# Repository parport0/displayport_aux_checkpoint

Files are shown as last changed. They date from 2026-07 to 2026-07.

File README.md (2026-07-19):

# displayport\_aux\_checkpoint 

An RP2040-powered box to be plugged between your computer and the monitor.

See also:

* [dvi_i2c_checkpoint](https://github.com/parport0/dvi_i2c_checkpoint)
* [ddcci_injector](https://github.com/parport0/ddcci_injector)
* [ddcci_dongle](https://github.com/parport0/ddcci_dongle)

Made to be manufactured at JLCPCB,

* JLC04161H-7628
* NanYa NP-155F

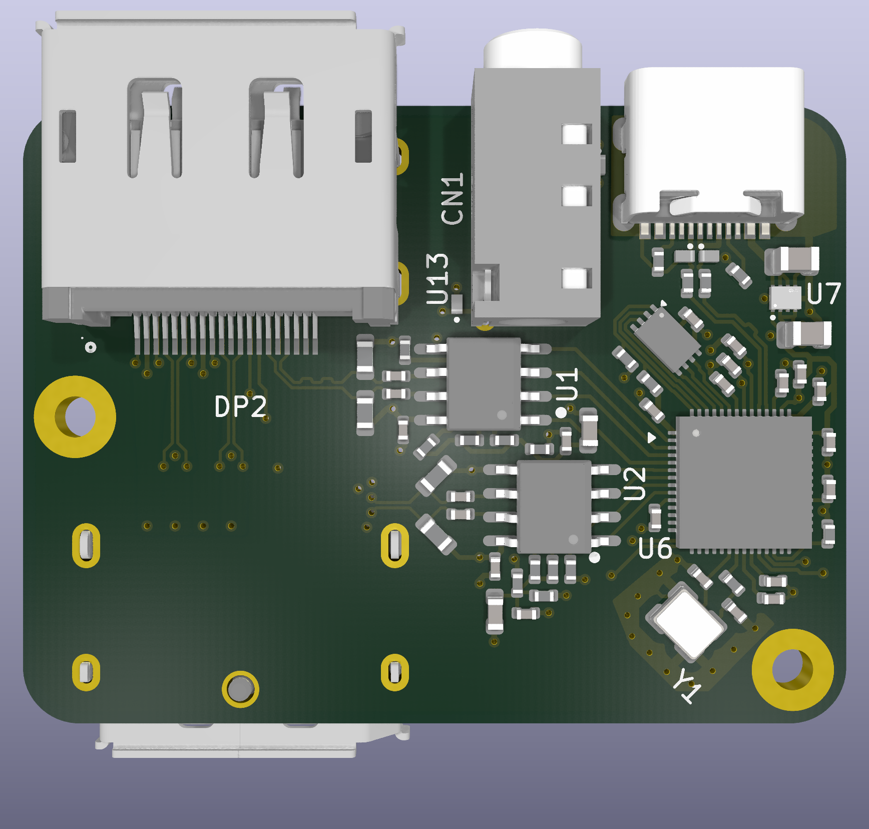
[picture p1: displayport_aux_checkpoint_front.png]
Front of the PCB


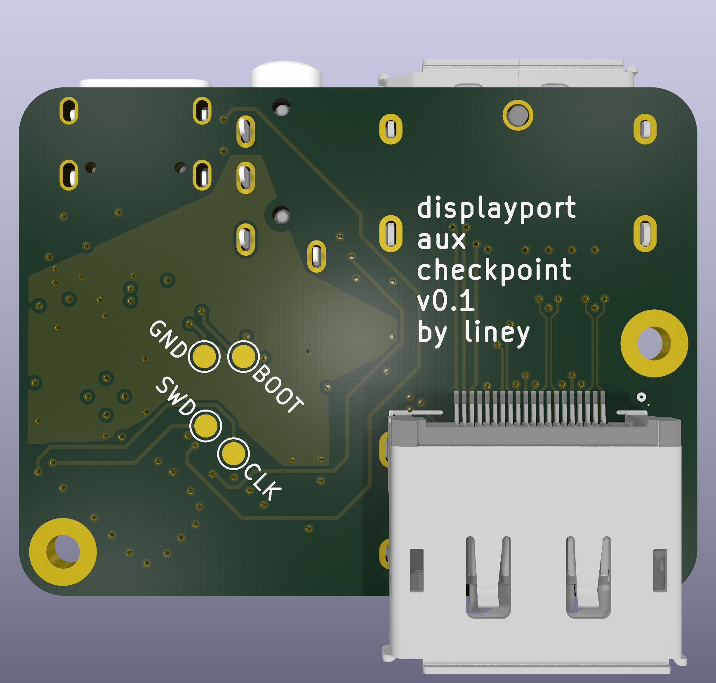
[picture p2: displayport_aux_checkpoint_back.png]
Back of the PCB


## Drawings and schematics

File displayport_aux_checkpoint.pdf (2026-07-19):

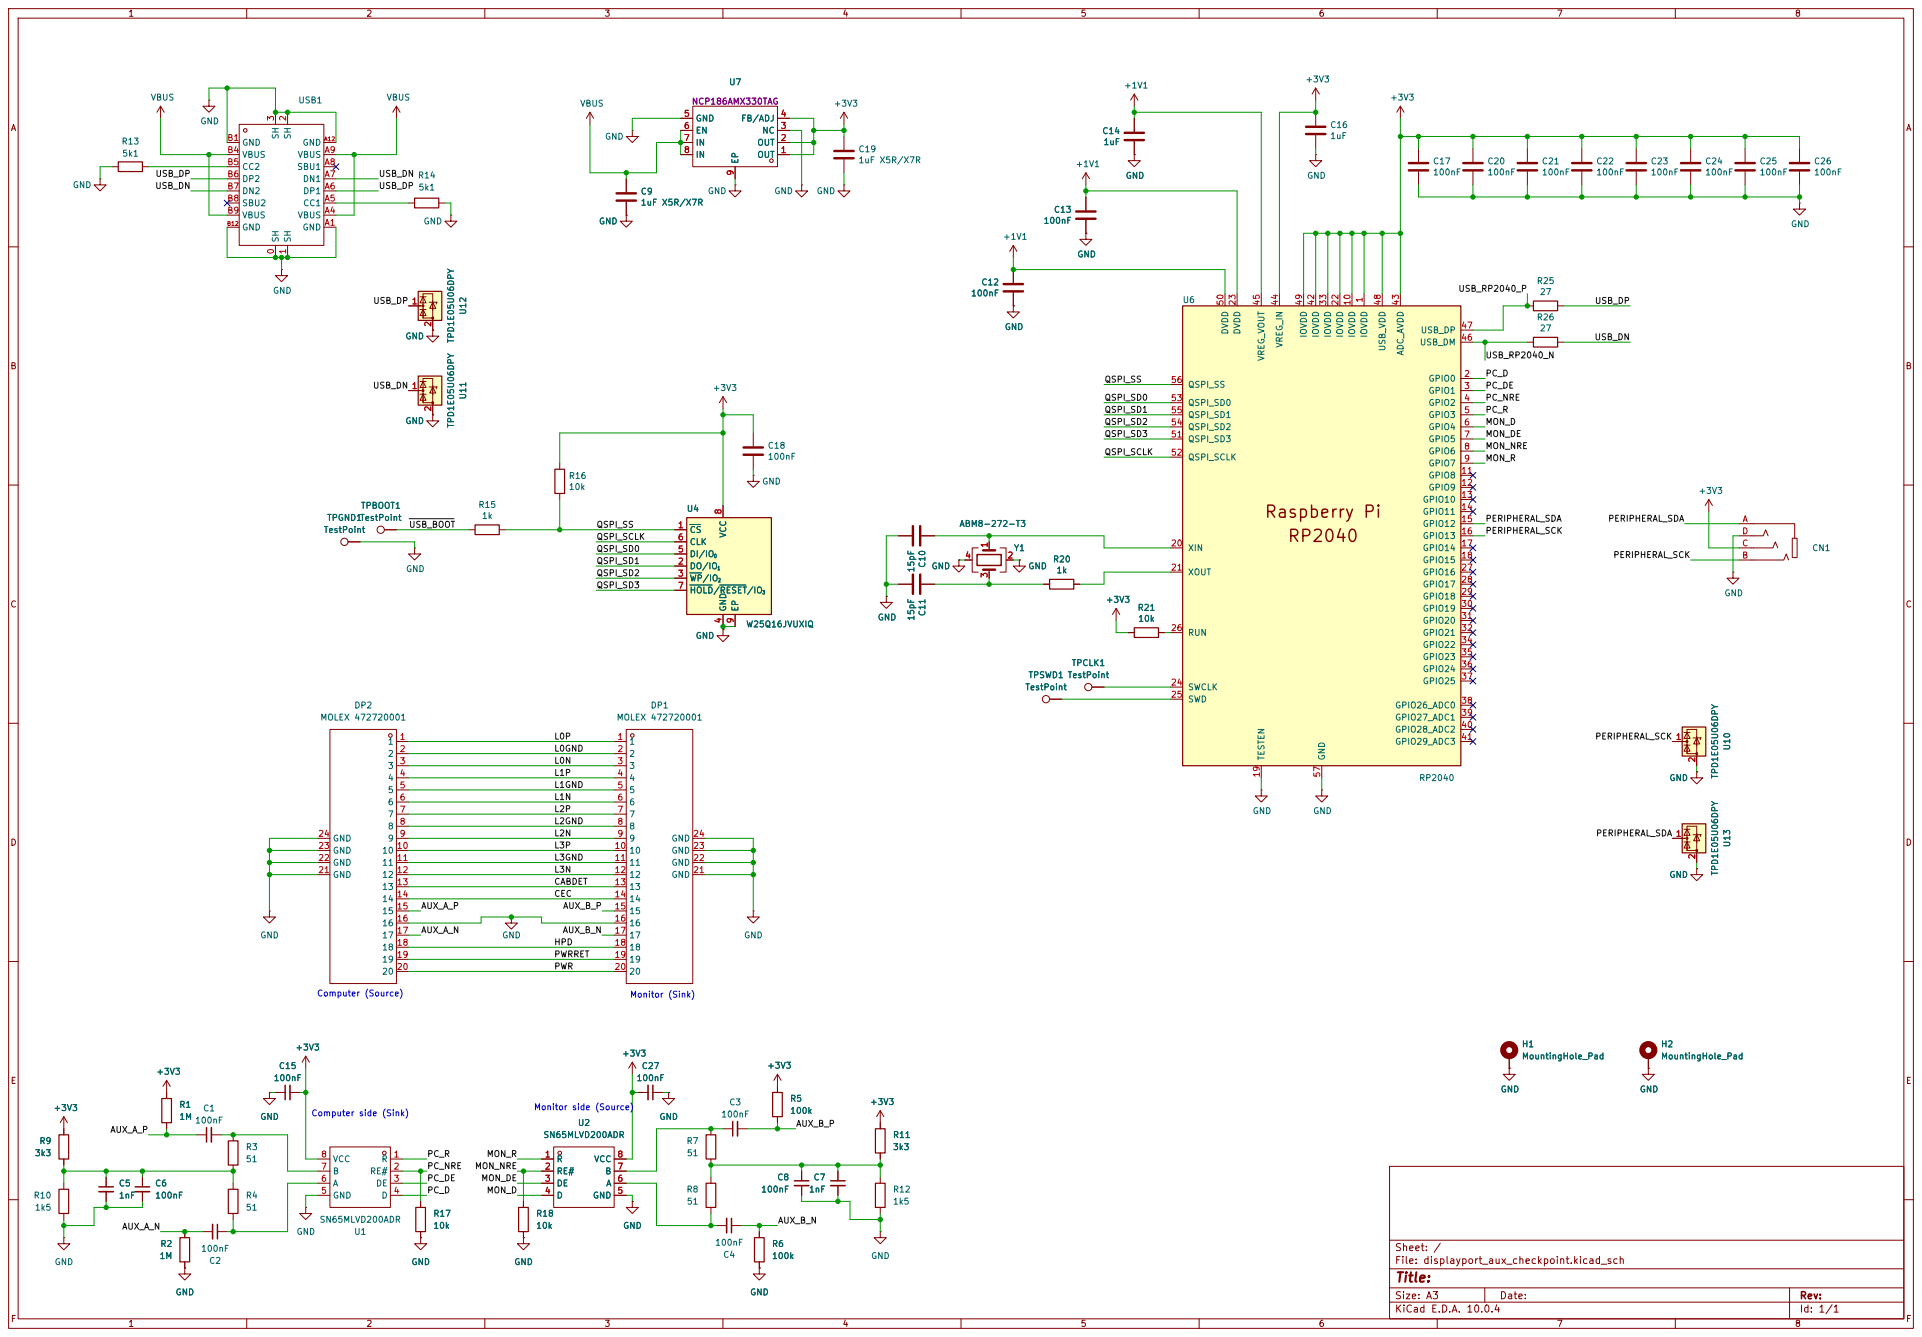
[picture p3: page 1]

3 GND A1 VBUS A4 CC1 A5 DP1 A6 DN1 A7 SBU1 A8 VBUS A9 GND A12 GND B1
GND

4 DI/IO0 5 CLK 6 HOLD/RESET/IO3 7 VCC

Size: A3 | Rev: | F Date:
KiCad E.D.A. 10.0.4 | Id: 1/1

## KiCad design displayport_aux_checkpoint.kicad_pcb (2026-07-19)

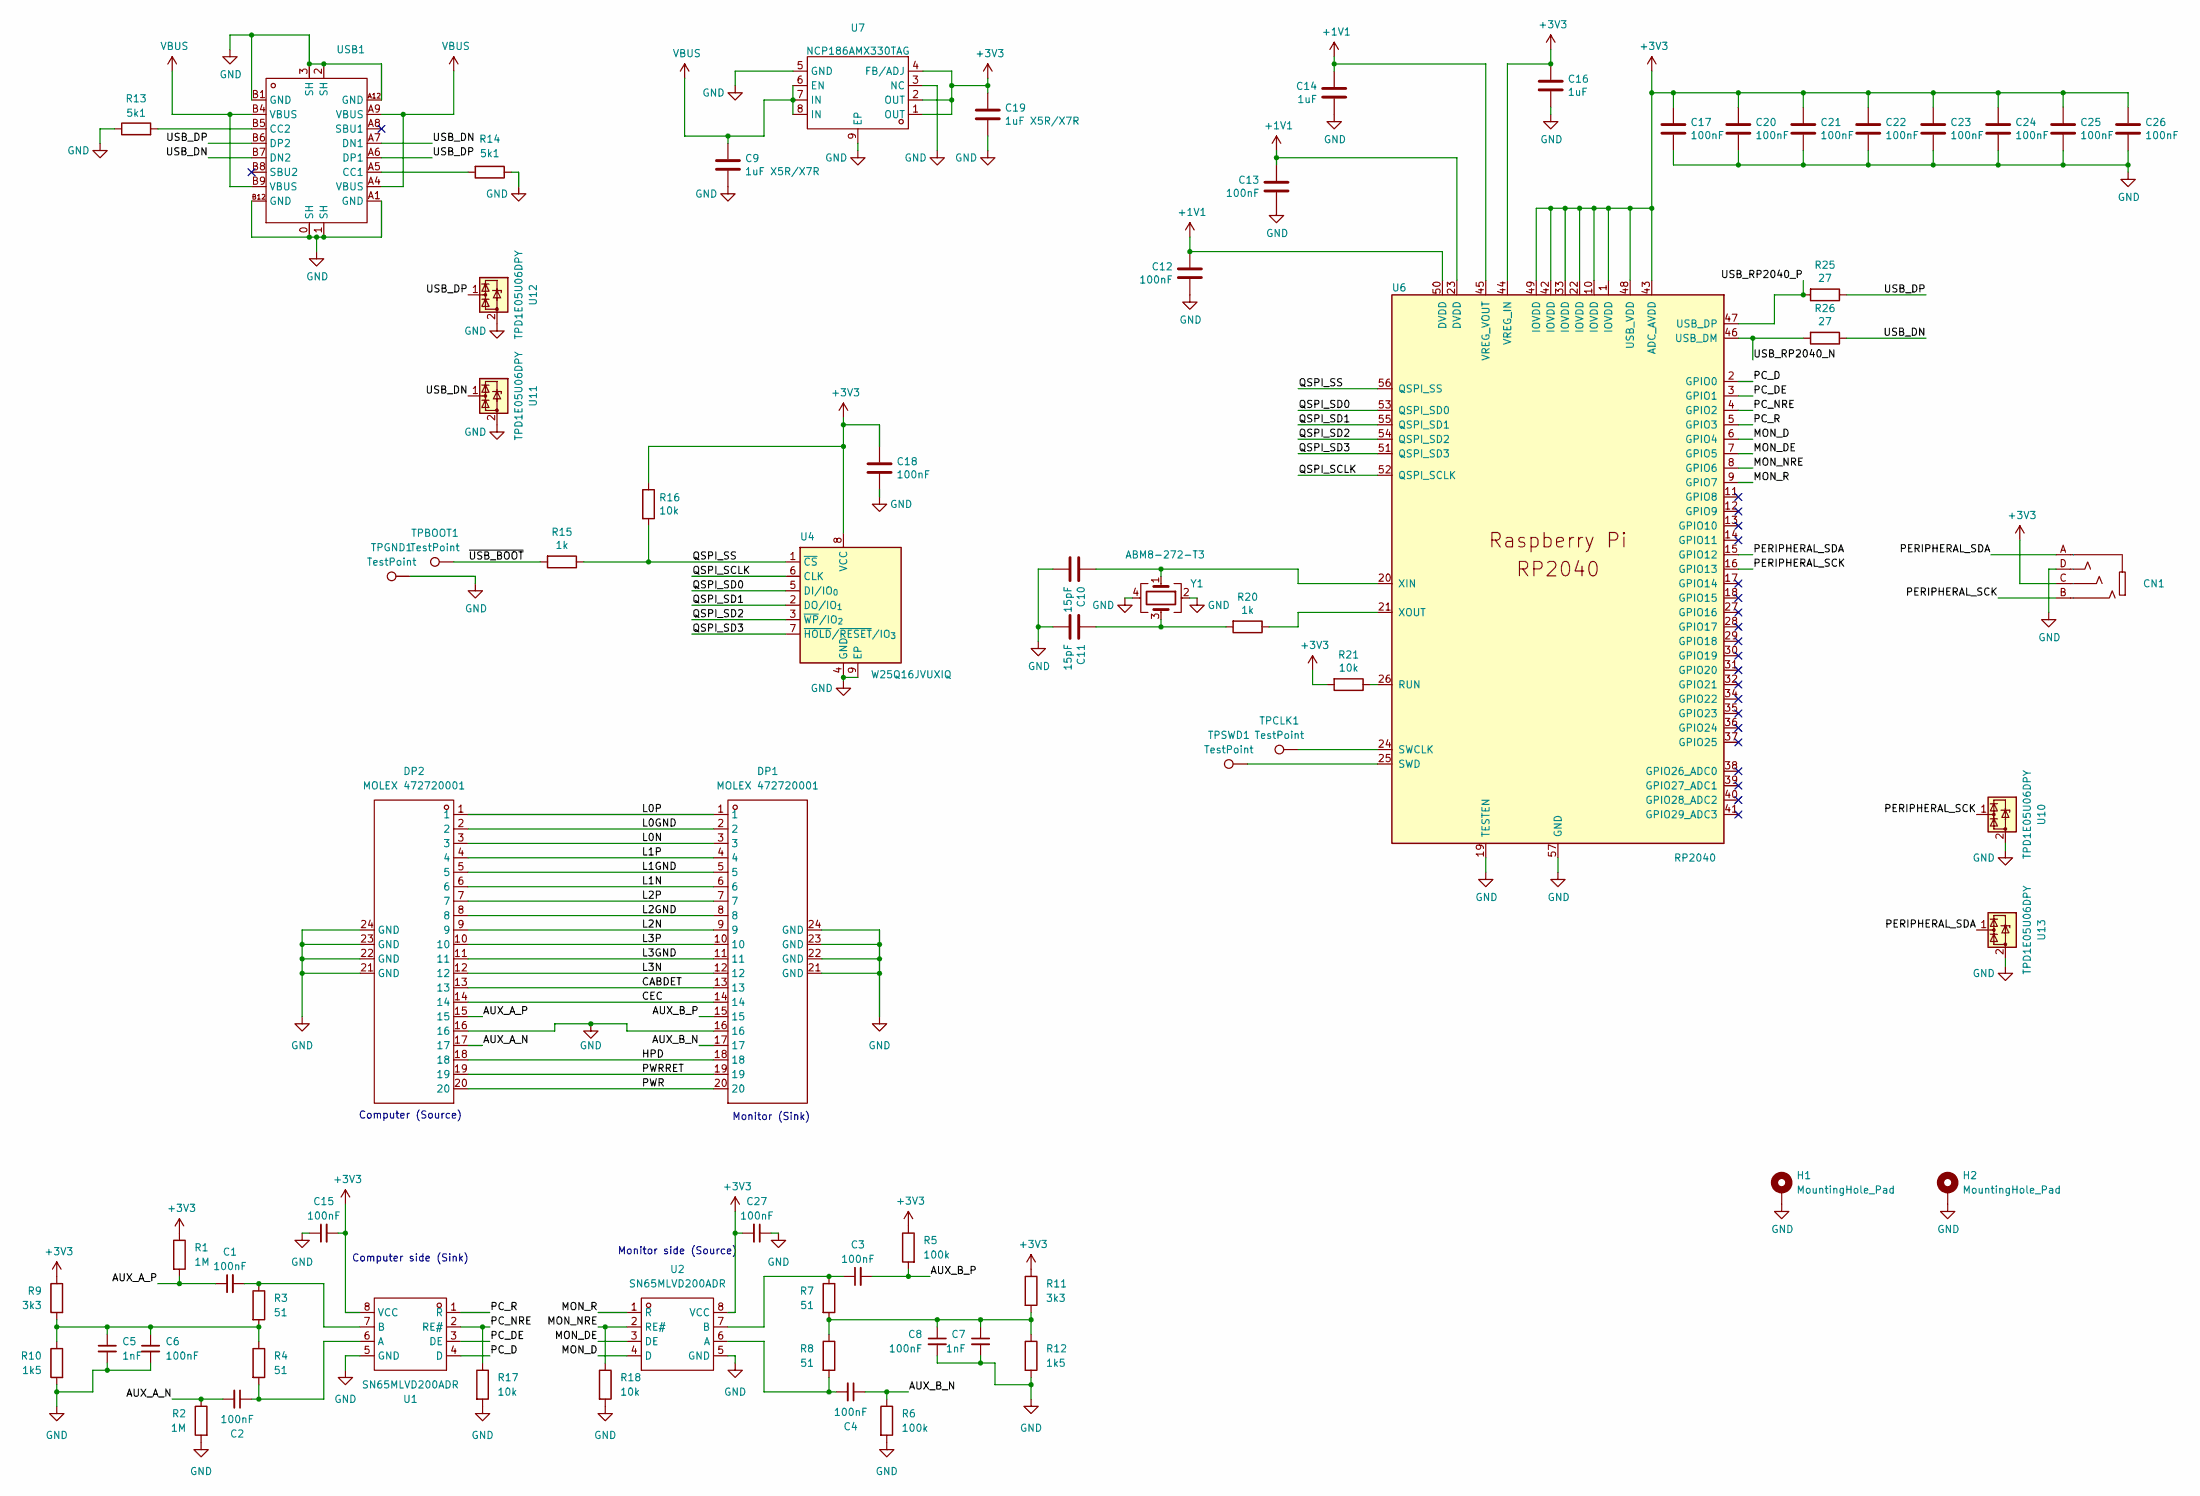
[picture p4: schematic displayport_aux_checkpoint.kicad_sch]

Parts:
C1, C2, C3, C4, C15, C27: 100nF; C_0402_1005Metric; Voltage 1kV; Tolerance 100%; LCSC Part C105883
C5, C7: 1nF; C_0402_1005Metric; LCSC Part C126532
C6, C8: 100nF; C_0603_1608Metric; LCSC Part C1591
C9, C19: 1uF X5R/X7R; C_0805_2012Metric; LCSC Part C28323
C10, C11: 15pF; C_0402_1005Metric; LCSC Part C1548
C12, C13, C17, C18, C20, C21, C22, C23, C24, C25, C26: 100nF; C_0402_1005Metric; LCSC Part C105883
C14, C16: 1uF; C_0402_1005Metric; LCSC Part C52923
CN1: AUDIO-TH_PJ-320A-4P-DIP; Manufacturer Part PJ-320A-4P DIP; LCSC Part Name 3.5mm耳机座
DP1, DP2: MOLEX 472720001; CONN-SMD_472720001; Manufacturer Part 472720001; LCSC Part Name 1.0mm间距显示端口插座组件
H1, H2: MountingHole_Pad; MountingHole_2.2mm_M2_Pad
R1, R2: 1M; R_0603_1608Metric; LCSC Part C107698
R3, R4, R7, R8: 51; R_0402_1005Metric; LCSC Part C853312
R5, R6: 100k; R_0603_1608Metric; LCSC Part C14675
R9, R11: 3k3; R_0402_1005Metric; LCSC Part C137992
R10, R12: 1k5; R_0402_1005Metric; LCSC Part C114451
R13, R14: 5k1; R_0402_1005Metric; LCSC Part C25905
R15, R20: 1k; R_0402_1005Metric; LCSC Part C11702
R16, R17, R18, R21: 10k; R_0402_1005Metric; LCSC Part C60490
R25, R26: 27; R_0402_1005Metric; LCSC Part C137890
TPBOOT1: TestPoint; TestPoint_Pad_D1.5mm
TPCLK1: TestPoint; TestPoint_Pad_D1.5mm
TPGND1: TestPoint; TestPoint_Pad_D1.5mm
TPSWD1: TestPoint; TestPoint_Pad_D1.5mm
U1, U2: SN65MLVD200ADR; SOIC-8_L5.0-W4.0-P1.27-LS6.0-BL; Manufacturer Part SN65MLVD200ADR; LCSC Part Name SN65MLVD200A 多点LVDS驱动器和接收器
U4: W25Q16JVUXIQ; Winbond_USON-8-1EP_3x2mm_P0.5mm_EP0.2x1.6mm; LCSC Part C2843335
U6: RP2040; QFN-56-1EP_7x7mm_P0.4mm_EP3.2x3.2mm; LCSC Part C2040
U7: XDFN-8_L1.6-W1.2-P0.40-BL-EP; Manufacturer Part NCP186AMX330TAG; LCSC Part Name NCP186AMX330TAG
U10, U11, U12, U13: TPD1E05U06DPY; Texas_DPY0002A_0.6x1mm_P0.65mm; LCSC Part C436349
USB1: USB-C_SMD-TYPE-C-31-M-12; LCSC Part Name Type-C 母 卧贴
Y1: ABM8-272-T3; Crystal_SMD_3225-4Pin_3.2x2.5mm; LCSC Part C20625731

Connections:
+1V1: C12.1, C13.1, C14.1, U6.23 (DVDD), U6.45 (VREG_VOUT), U6.50 (DVDD)
+3V3: C15.2, C16.1, C17.1, C18.1, C19.1, C20.1, C21.1, C22.1, C23.1, C24.1, C25.1, C26.1, C27.2, CN1.C, R1.1, R5.1, R9.1, R11.1, R16.1, R21.2, U1.8 (VCC), U2.8 (VCC), U4.8 (VCC), U6.1 (IOVDD), U6.10 (IOVDD), U6.22 (IOVDD), U6.33 (IOVDD), U6.42 (IOVDD), U6.43 (ADC_AVDD), U6.44 (VREG_IN), U6.48 (USB_VDD), U6.49 (IOVDD), U7.1 (OUT), U7.2 (OUT), U7.4 (FB/ADJ)
/AUX_A_N: C2.2, DP2.17, R2.1
/AUX_A_P: C1.1, DP2.15, R1.2
/AUX_B_N: C4.1, DP1.17, R6.1
/AUX_B_P: C3.2, DP1.15, R5.2
/CABDET: DP1.13, DP2.13
/CEC: DP1.14, DP2.14
/HPD: DP1.18, DP2.18
/L0GND: DP1.2, DP2.2
/L0N: DP1.3, DP2.3
/L0P: DP1.1, DP2.1
/L1GND: DP1.5, DP2.5
/L1N: DP1.6, DP2.6
/L1P: DP1.4, DP2.4
/L2GND: DP1.8, DP2.8
/L2N: DP1.9, DP2.9
/L2P: DP1.7, DP2.7
/L3GND: DP1.11, DP2.11
/L3N: DP1.12, DP2.12
/L3P: DP1.10, DP2.10
/MON_D: U2.4 (D), U6.6 (GPIO4)
/MON_DE: U2.3 (DE), U6.7 (GPIO5)
/MON_NRE: R18.1, U2.2 (RE#), U6.8 (GPIO6)
/MON_R: U2.1 (R), U6.9 (GPIO7)
/PC_D: U1.4 (D), U6.2 (GPIO0)
/PC_DE: U1.3 (DE), U6.3 (GPIO1)
/PC_NRE: R17.1, U1.2 (RE#), U6.4 (GPIO2)
/PC_R: U1.1 (R), U6.5 (GPIO3)
/PERIPHERAL_SCK: CN1.B, U6.16 (GPIO13), U10.1 (I/O)
/PERIPHERAL_SDA: CN1.A, U6.15 (GPIO12), U13.1 (I/O)
/PWR: DP1.20, DP2.20
/PWRRET: DP1.19, DP2.19
/QSPI_SCLK: U4.6 (CLK), U6.52 (QSPI_SCLK)
/QSPI_SD0: U4.5 (DI/IO_{0}), U6.53 (QSPI_SD0)
/QSPI_SD1: U4.2 (DO/IO_{1}), U6.55 (QSPI_SD1)
/QSPI_SD2: U4.3 (~WP/IO_{2}), U6.54 (QSPI_SD2)
/QSPI_SD3: U4.7 (~HOLD/~RESET/IO_{3}), U6.51 (QSPI_SD3)
/QSPI_SS: R15.1, R16.2, U4.1 (~CS), U6.56 (QSPI_SS)
/USB_DN: R26.1, U11.1 (I/O), USB1.A7 (DN1), USB1.B7 (DN2)
/USB_DP: R25.1, U12.1 (I/O), USB1.A6 (DP1), USB1.B6 (DP2)
/USB_RP2040_N: R26.2, U6.46 (USB_DM)
/USB_RP2040_P: R25.2, U6.47 (USB_DP)
/~USB_BOOT: R15.2, TPBOOT1.1; also elsewhere on the board
GND: C5.2, C6.2, C7.2, C8.2, C9.2, C10.2, C11.2, C12.2, C13.2, C14.2, C15.1, C16.2, C17.2, C18.2, C19.2, C20.2, C21.2, C22.2, C23.2, C24.2, C25.2, C26.2, C27.1, CN1.D, DP1.16, DP1.21 (GND), DP1.22 (GND), DP1.23 (GND), DP1.24 (GND), DP2.16, DP2.21 (GND), DP2.22 (GND), DP2.23 (GND), DP2.24 (GND), H1.1 (1_1), H2.1 (1_1), R2.2, R6.2, R10.2, R12.2, R13.1, R14.1, R17.2, R18.2, TPGND1.1, U1.5 (GND), U2.5 (GND), U4.4 (GND), U4.9 (EP), U6.19 (TESTEN), U6.57 (GND), U7.3 (NC), U7.5 (GND), U7.9 (EP), U10.2 (GND), U11.2 (GND), U12.2 (GND), U13.2 (GND), USB1.0 (SH), USB1.1 (SH), USB1.2 (SH), USB1.3 (SH), USB1.A1 (GND), USB1.A12 (GND), USB1.B1 (GND), USB1.B12 (GND), Y1.2, Y1.4; also elsewhere on the board
unnamed: C5.1, C6.1, R3.2, R4.1, R9.2, R10.1
unnamed: C7.1, C8.1, R7.2, R8.1, R11.2, R12.1
unnamed: C11.1, R20.2, Y1.3
unnamed: C2.1, R4.2, U1.6 (A)
unnamed: C1.2, R3.1, U1.7 (B)
unnamed: C4.2, R8.2, U2.6 (A)
unnamed: C3.1, R7.1, U2.7 (B)
unnamed: R21.1, U6.26 (RUN)
unnamed 53: TPCLK1.1, U6.24 (SWCLK); also elsewhere on the board
unnamed 54: TPSWD1.1, U6.25 (SWD); also elsewhere on the board
unnamed: C10.1, U6.20 (XIN), Y1.1
unnamed: R20.1, U6.21 (XOUT)
unnamed: R14.2, USB1.A5 (CC1)
unnamed: R13.2, USB1.B5 (CC2)
VBUS: C9.1, U7.6 (EN), U7.7 (IN), U7.8 (IN), USB1.A4 (VBUS), USB1.A9 (VBUS), USB1.B4 (VBUS), USB1.B9 (VBUS)

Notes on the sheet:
Computer side (Sink)
Computer (Source)
Monitor side (Source)
Monitor (Sink)

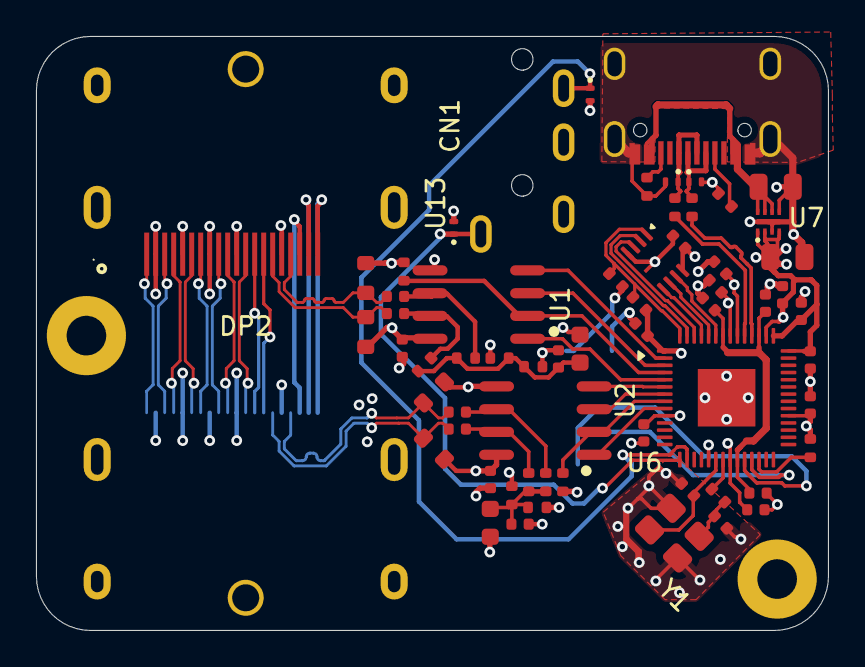
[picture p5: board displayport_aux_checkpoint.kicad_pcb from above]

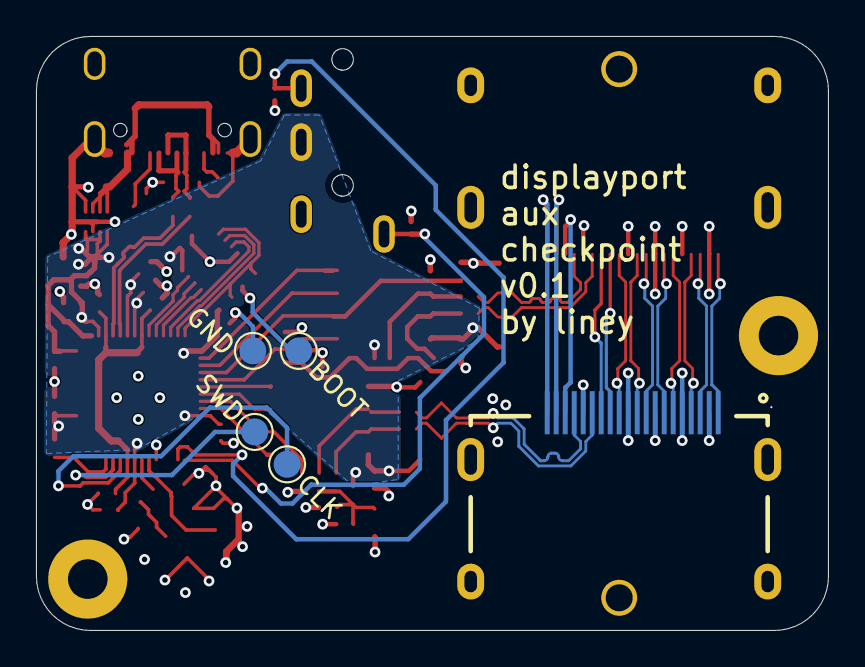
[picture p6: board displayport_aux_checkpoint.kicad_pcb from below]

Board: 4 copper layers, 44.0 x 33.0 mm, 69 parts (5 on the bottom side), 60 nets.

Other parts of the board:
BOOT: TestPoint; TestPoint_Pad_D1.5mm
CLK: TestPoint; TestPoint_Pad_D1.5mm
GND: TestPoint; TestPoint_Pad_D1.5mm
SWD: TestPoint; TestPoint_Pad_D1.5mm

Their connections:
/~USB_BOOT: BOOT.1 (1_1); also elsewhere on the board
GND: GND.1 (1_1); also elsewhere on the board
unnamed 53: CLK.1 (1_1); also elsewhere on the board
unnamed 54: SWD.1 (1_1); also elsewhere on the board
